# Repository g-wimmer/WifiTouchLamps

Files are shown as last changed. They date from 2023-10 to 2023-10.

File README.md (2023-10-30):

This is the code for a pair of wifi/tor enabled touch lamps. A pair of two lamps can be connected to any two different wifi networks and be able to interactivly syncronize their colors. Touching one lamp will cause the other to change to the first lamps color. No central server is required for the lights to communicate. The dial on the side of the lamp is used to control the color of your lamp.

Lamp Hardware Specification:

Hardware wise, the two lamps are identical. They consist of the following:<br>
Raspberry Pi Zero W<br>
Capacitive Touch Sensor<br>
Potentiometer<br>
Resistor-Capacitor Cirtcuit (to serve as an analog to digital for the potentiometer)<br>
Neopizel Light Ring<br>
3 Volt to 5 Volt step up circuit to power the neopixel<br>
3D Printed Housing to hold the electronics. The top half is printed in a white filament to serve as a diffuser for the light (files included in repo)<br>

The two lamps are divided into client and server. Each can operate independently of the other if the other lamp is offline. 

The server is a simple http python server that constantly waits for a color change from the client. Upon recieving notice that the client has changed color, the server will update its own. The client periodically sends a heartbeat to the server even if no color changes have occured. The server will hold onto this http request and wait to respond for a period of time. If the server changes its color, it will immeditaly respond to the held request from the client to inform it of this change. This system was put in place to ensure that the lamps are not repeatedly bouncing requests back and forth continously and instead only communicate around once every minute.

The lamps do not operate on the clearnet. Instead the server makes use of the Tor network to host its http server. This was done for multiple reasons. The first of which was security. By using an onion link, only the client which is hardcoded with the link, will be able to find this server. This adds a layer of security and prevents potential DDOS attacks. The second reason is that the Tor network will allow the webserver to function regardless of where it is located and without control over the network it is connected to. A normal webserver would require network administrator rights to provide a fixed ip, port forwarding and other such conveniences. The tor network allows the client to always find the server if the server is connected to the Tor network. By not needing network administration powers, these lamps to not require some central server to communicate. Removing a central server or some dependence on a cloud service was one of the main goals of this project.

Both lamps make use of a potentiometer to control the color of the neopixels. The RC-circuit works as an analog to digital converter for the potentiometer. The potentiometer will now roughly serve as a dial that controls the colors. To smooth the values from the rc-circuit, the lamps use a simple moving average of the inputs.

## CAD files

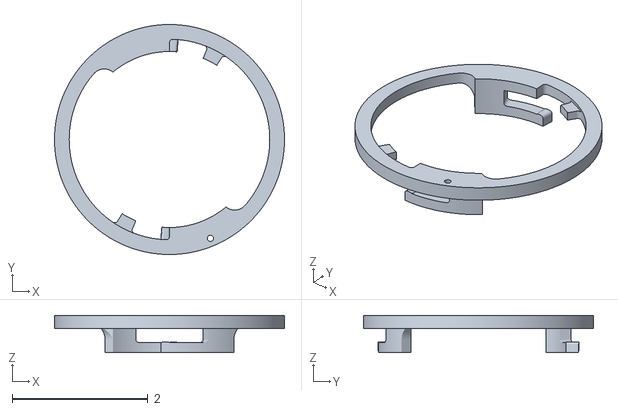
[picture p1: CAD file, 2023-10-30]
lock.stl
3.39 x 3.39 x 0.551

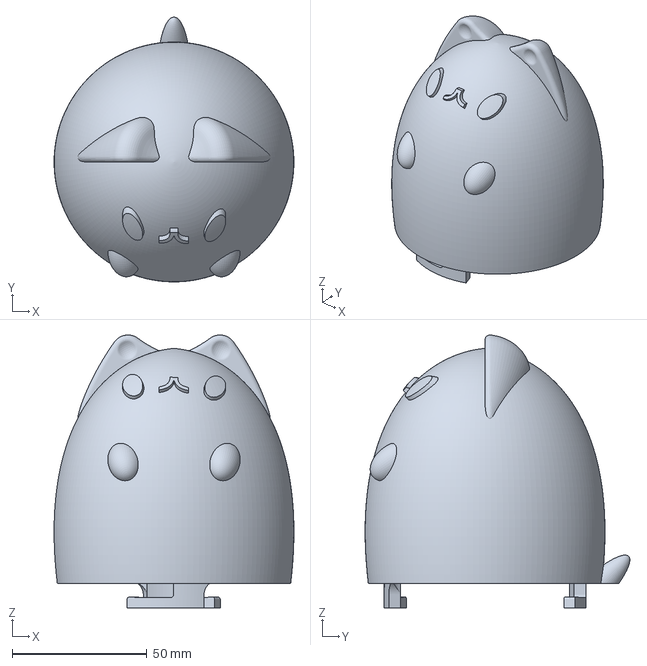
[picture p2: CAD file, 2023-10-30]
lockandcatslice.3mf
89.0 x 98.3 x 101.3 mm

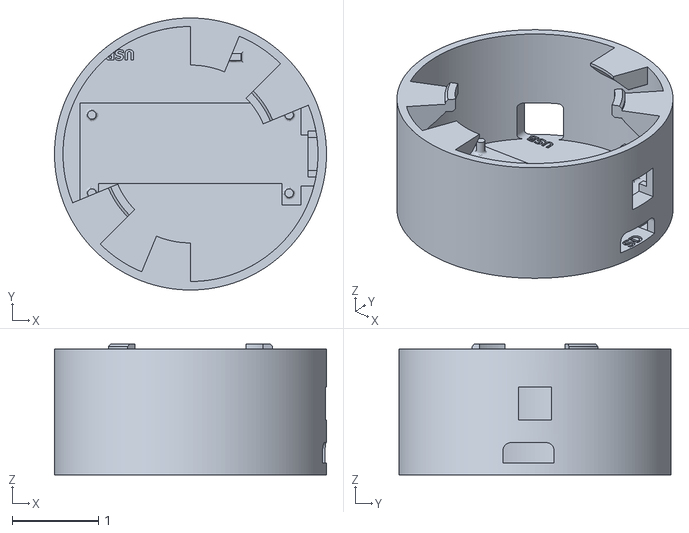
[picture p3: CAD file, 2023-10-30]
base.stl
3.15 x 3.15 x 1.52

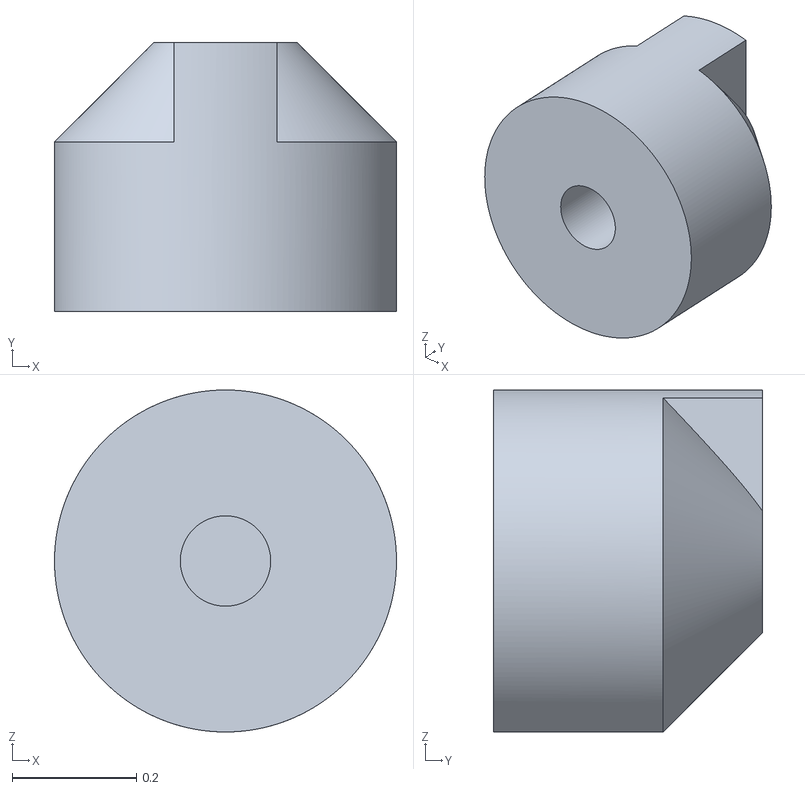
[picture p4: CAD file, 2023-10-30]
knob.stl
0.551 x 0.433 x 0.551

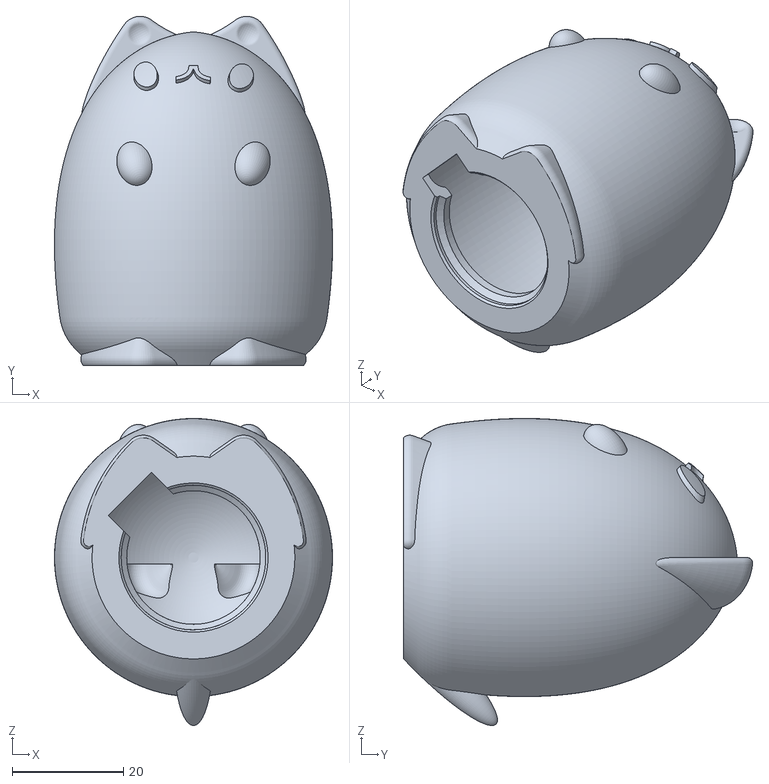
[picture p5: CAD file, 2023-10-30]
pusheen_body.STL
50.0 x 62.8 x 55.2

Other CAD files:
base.ipt
knob.ipt
lock.ipt

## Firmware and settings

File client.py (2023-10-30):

import time
import RPi.GPIO as GPIO
import board
import neopixel
import threading
import requests
from requests.exceptions import Timeout

session = requests.session()
session.proxies = {}
session.proxies['http'] = 'socks5h://localhost:9050'
session.proxies['https'] = 'socks5h://localhost:9050'

url = "" #insert onion address of server here
GPIO.setmode(GPIO.BCM)
pin_a = 23
pin_b = 24
pin_c = 17
pixel_pin = board.D18
num_pixels = 24
ORDER = neopixel.RGB

pixels = neopixel.NeoPixel(
    pixel_pin, num_pixels, brightness=0.4, auto_write=False, pixel_order=ORDER
)
def updatecolor(old_color, new_color, update_time): #smooth change in color
    global current_color_time
    current_color_time[0] = new_color
    current_color_time[1] = update_time
    steps = 20
    diff = (old_color - new_color)/steps
    for x in range(steps):
        pixels.fill(wheel(int(old_color - (diff*x))))
        pixels.show()
        time.sleep(.02)
    pixels.fill(wheel(new_color))
    pixels.show()


def wheel(pos):
    if pos < 0 or pos > 255:
        r = g = b = 0
    elif pos < 85:
        r = int(pos * 3)
        g = int(255 - pos * 3)
        b = 0
    elif pos < 170:
        pos -= 85
        r = int(255 - pos * 3)
        g = 0
        b = int(pos * 3)
    else:
        pos -= 170
        r = 0
        g = int(pos * 3)
        b = int(255 - pos * 3)
    return (r, g, b) if ORDER in (neopixel.RGB, neopixel.GRB) else (r, g, b, 0)

def discharge():
    GPIO.setup(pin_a, GPIO.IN)
    GPIO.setup(pin_b, GPIO.OUT)
    GPIO.output(pin_b, False)
    time.sleep(.005)

def analog_read():
    discharge()
    return charge_time()

def charge_time():
    GPIO.setup(pin_a, GPIO.OUT)
    GPIO.setup(pin_b, GPIO.IN)
    count = 0
    GPIO.output(pin_a, True)
    while not GPIO.input(pin_b):
        count += 1
    return count

def startupsequence(): #fun little startup light sweep
    for x in range(num_pixels):
        pixels[x] = (100,100,100)
        time.sleep(.02)
        pixels.show()
    for x in range(num_pixels):
        pixels[x] = (0,0,0)
        pixels.show()
        time.sleep(.02)

def readpot(): #is constantly reading the potentiometer value
    global potvalue
    potvalue = 0
    slope = 255 / (111 - 1) #111 and 3 are the range of values read from the potentiometer
    try:
        while True:
            readvalue = analog_read()
            if readvalue > 111: # prevent it from maxing out
                readvalue = 90
            readvalue = (slope * (readvalue - 1)) #this converts the potentiometer value to a value in the range of 0-255
            potvalue = int((readvalue *.7) + (potvalue *.3)) # to smooth out the jumpy values
            #potvalue = int(readvalue)
            time.sleep(1)
    except KeyboardInterrupt:
        pass

def waitfortouch():
    global potvalue
    global current_color_time
    GPIO.setup(pin_c, GPIO.IN)
    try:
        while True:
            if GPIO.input(pin_c):
                if abs(potvalue - current_color_time[0]) > 2: #only change colors if the change is significant
                    updatecolor(current_color_time[0], potvalue, round(time.time(),2))
                    try:
                        r = session.get(url+"?changedtime="+str(current_color_time[1])+"&clientcolor="+str(current_color_time[0]), timeout=9)
                        if(r.status_code == 200):
                            newc = int(r.text[r.text.index("Color:")+6:r.text.index("endcolor")])
                            newt = float(r.text[r.text.index("time:")+5:r.text.index("endtime")])
                            if round(newt,1) > round(current_color_time[1],1): #incase the server has updated the color during the time that the requests was being sent
                                updatecolor(current_color_time[0], newc, newt)
                        elif r.status_code != 201:
                            print("Theres been an error: "+int(r.status_code))
                    except Timeout: #flashes red to indicate that it was unable to reach the hostlamp
                        pixels.fill((0,0,0))
                        pixels.show()
                        time.sleep(.25)
                        pixels.fill((200,10,10))
                        pixels.show()
                        time.sleep(.25)
                        pixels.fill(wheel(current_color_time[0]))
                        pixels.show()
                    except requests.exceptions.ConnectionError:
                        pixels.fill((0,0,0))
                        pixels.show()
                        time.sleep(.2)
                        pixels.fill((10,100,10))
                        pixels.show()
                        time.sleep(.2)
                        pixels.fill(wheel(current_color_time[0]))
                        pixels.show()
                        print("Lost connection to host. Retrying in 15 seconds")
                        time.sleep(.3)
            time.sleep(.1)
    except KeyboardInterrupt:
        pass

def startclient():
    try:
        timeouttime = 11
        startupsequence()
        while True:
            time.sleep(.1)
            try:
                r = session.get(url+"?changedtime="+str(current_color_time[1])+"&clientcolor="+str(current_color_time[0]), timeout=timeouttime)
                timeouttime = 11
                if r.status_code == 200:#200 indicates that the color has been updated on the host
                    newc = int(r.text[r.text.index("Color:")+6:r.text.index("endcolor")])
                    newt = float(r.text[r.text.index("time:")+5:r.text.index("endtime")])
                    print("time from server:"+str(newt))
                    print("last updated time:"+str(current_color_time[1]))
                    if round(newt,2) > round(current_color_time[1],2):
                        updatecolor(current_color_time[0], newc, newt)
                elif r.status_code != 201: #201 is for when they are in sync so if it isnt 200 or 201 there has been an error
                    print("There has been an error: "+str(r.status_code))
                else:
                    time.sleep(.05)
            except Timeout: #increase time between requests
                print("Couldnt reach the server increasing timeouttime")
                if timeouttime == 11:
                    timeouttime = 30
                elif timeouttime == 30:
                    timeouttime = 40
            except requests.exceptions.ConnectionError:
                print("Lost connection to host. Retrying in 20 seconds")
                time.sleep(20)
    except KeyboardInterrupt:
        pass


if __name__ == "__main__":
    global current_color_time
    current_color_time = [0,0.0]
    t1 = threading.Thread(target=startclient)
    t2 = threading.Thread(target=waitfortouch)
    t3 = threading.Thread(target=readpot)
    t1.start()
    t2.start()
    t3.start()
    t1.join()
    t2.join()
    t3.join()
    print("Exiting client")

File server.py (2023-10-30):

"""
Server client for the wifi enabled tor based touch lamp

By Gabriel Wimmer
"""

from http.server import BaseHTTPRequestHandler, ThreadingHTTPServer
import time
import RPi.GPIO as GPIO
import board
import neopixel
import threading

hostName = "localhost"
serverPort = 80
pixel_pin = board.D18
num_pixels = 24
ORDER = neopixel.RGB

GPIO.setmode(GPIO.BCM)
pin_a = 23
pin_b = 24
pin_c = 17
pixels = neopixel.NeoPixel(
    pixel_pin, num_pixels, brightness=0.4, auto_write=False, pixel_order=ORDER
)

def wheel(pos):
    # Input a value 0 to 255 to get a color value.
    # The colours are a transition r - g - b - back to r.
    if pos < 0 or pos > 255:
        r = g = b = 0
    elif pos < 85:
        r = int(pos * 3)
        g = int(255 - pos * 3)
        b = 0
    elif pos < 170:
        pos -= 85
        r = int(255 - pos * 3)
        g = 0
        b = int(pos * 3)
    else:
        pos -= 170
        r = 0
        g = int(pos * 3)
        b = int(255 - pos * 3)
    return (r, g, b) if ORDER in (neopixel.RGB, neopixel.GRB) else (r, g, b, 0)

def startupsequence(): #fun little startup light sweep
    for x in range(num_pixels):
        pixels[x] = (100,100,100)
        time.sleep(.02)
        pixels.show()
    for x in range(num_pixels):
        pixels[x] = (0,0,0)
        pixels.show()
        time.sleep(.02)

def updatecolor(old_color, new_color, update_time): #smooth change in color
    global current_color_time
    steps = 20
    diff = (old_color - new_color)/steps
    for x in range(steps):
        pixels.fill(wheel(int(old_color - (diff*x))))
        pixels.show()
        time.sleep(.02)
    pixels.fill(wheel(new_color))
    pixels.show()
    current_color_time[0] = new_color
    current_color_time[1] = update_time


class MyServer(BaseHTTPRequestHandler):
    def do_GET(self):
        if "getcurrentcolor" in self.path:
            if "changedtime=" not in self.path or "clientcolor=" not in self.path:
                print("request didnt contain the correct queries")
                self.send_response(400)
                self.send_header("Content-type", "text/html")
                self.end_headers()
                self.wfile.write(bytes("query did not contain the correct variables", "utf-8"))
                return
            client_changed_time = float(self.path[self.path.index("changedtime=")+12:self.path.index("&clientcolor=")]) #gets the unix time code for when the clients color was changed
            client_color = int(self.path[self.path.index("&clientcolor=")+13:])
            if round(client_changed_time,2) < round(current_color_time[1],2):
                self.send_response(200)
                self.send_header("Content-type", "text/html")
                self.end_headers()
                self.wfile.write(bytes("<html><head><title>Gabe rocks</title></head>", "utf-8"))
                self.wfile.write(bytes("<p>Color:%dendcolor</p>" % current_color_time[0], "utf-8"))
                self.wfile.write(bytes("<p>Update time:%fendtime</p>" % current_color_time[1], "utf-8"))
                self.wfile.write(bytes("</html>", "utf-8"))
                return
            elif round(client_changed_time,2) == round(current_color_time[1],2): #if the lamps are synced, wait for changes to respond
                for x in range(90):
                    time.sleep(.1)
                    if round(client_changed_time,2) < round(current_color_time[1],2):
                        self.send_response(200)
                        self.send_header("Content-type", "text/html")
                        self.end_headers()
                        self.wfile.write(bytes("<html><head><title>Gabe rocks</title></head>", "utf-8"))
                        self.wfile.write(bytes("<p>Color:%dendcolor</p>" % current_color_time[0], "utf-8"))
                        self.wfile.write(bytes("<p>Update time:%fendtime</p>" % current_color_time[1], "utf-8"))
                        self.wfile.write(bytes("</html>", "utf-8"))
                        return
                self.send_response(201) #201 code indicates that nothing has changed
                self.send_header("Content-type", "text/html")
                self.end_headers()
                self.wfile.write(bytes("<html><head><title>Gabe rocks</title></head>", "utf-8"))
                self.wfile.write(bytes("<p>Color:%dendcolor</p>" % current_color_time[0], "utf-8"))
                self.wfile.write(bytes("<p>Update time:%fendtime</p>" % current_color_time[1], "utf-8"))
                self.wfile.write(bytes("</html>", "utf-8"))
                return
            else: #if the client has updated the color more recently, update the hosts color
                updatecolor(current_color_time[0], client_color, client_changed_time)
                self.send_response(201)
                self.send_header("Content-type", "text/html")
                self.end_headers()
                self.wfile.write(bytes("<html><head><title>Gabe rocks</title></head>", "utf-8"))
                self.wfile.write(bytes("<p>Color:%dendcolor</p>" % client_color, "utf-8"))
                self.wfile.write(bytes("<p>Update time:%fendtime</p>" % client_changed_time, "utf-8"))
                self.wfile.write(bytes("</html>", "utf-8"))
                return
        else:
            self.send_response(203)
            self.send_header("Content-type", "text/html")
            self.end_headers()
            self.wfile.write(bytes("<html><head><title>Test Page</title></head>", "utf-8"))
            self.wfile.write(bytes("<p>Request: %s</p>" % self.path, "utf-8"))
            self.wfile.write(bytes("<body>", "utf-8"))
            self.wfile.write(bytes("<p>This is an example web server.</p>", "utf-8"))
            self.wfile.write(bytes("</body></html>", "utf-8"))

def waitfortouch():
    global potvalue
    global current_color_time
    GPIO.setup(pin_c, GPIO.IN)
    try:
        while True:
            if GPIO.input(pin_c):
                if abs(potvalue - current_color_time[0]) > 2: #only change colors if the change is significant
                    updatecolor(current_color_time[0], potvalue, round(time.time(),2))
            time.sleep(.1)
    except KeyboardInterrupt:
        pass

def startserver():
    webServer = ThreadingHTTPServer((hostName, serverPort), MyServer)
    print("Server started http://%s:%s" % (hostName, serverPort))
    startupsequence()
    try:
        webServer.serve_forever()
    except KeyboardInterrupt:
        pass
    webServer.server_close()
    print("Server stopped.")

def discharge():
    GPIO.setup(pin_a, GPIO.IN)
    GPIO.setup(pin_b, GPIO.OUT)
    GPIO.output(pin_b, False)
    time.sleep(.005)

def charge_time():
    GPIO.setup(pin_a, GPIO.OUT)
    GPIO.setup(pin_b, GPIO.IN)
    count = 0
    GPIO.output(pin_a, True)
    while not GPIO.input(pin_b):
        count += 1
    return count

def analog_read():
    discharge()
    return charge_time()
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
